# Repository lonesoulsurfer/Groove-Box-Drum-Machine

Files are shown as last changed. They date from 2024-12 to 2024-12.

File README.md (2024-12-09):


# Groove Box Drum Machine
An Arduino Nano based drum machine based on the awesome DrumKid build (https://github.com/mattybrad/drumkid) by Matt Bradshaw.  My version includes 3 X trigger outputs so you can sync with other synths.  I've also designed it so it will fit into any Eurorack and can be powered by either a standard 16 pin Eurorack power input or a 9V JST connector.

You can find a step by step guide on my Instructables page on how to build your own - https://www.instructables.com/Groove-Box-Arduino-Nano-Drum-Machine/

I have also posted a video on my YouTube page - https://youtu.be/VaNvsRpYE2A

The main goal with building this module is to create my own 'simple to build' modular synth. I wanted to keep everything as easy as possble with each module built with the following aims:

 - Can be powered by 9V (and 12V)
 - Easy to build with minimum components
 - Use Arduino to keep it simple (plus it helps to keep the components down and everything in tune)
 - Can fit into any modular synth Eurorck (include the ability to power the module via normal module power sources)
 - Has to sound great!
- Lastly, it should be portable and be powered from a 9V battery



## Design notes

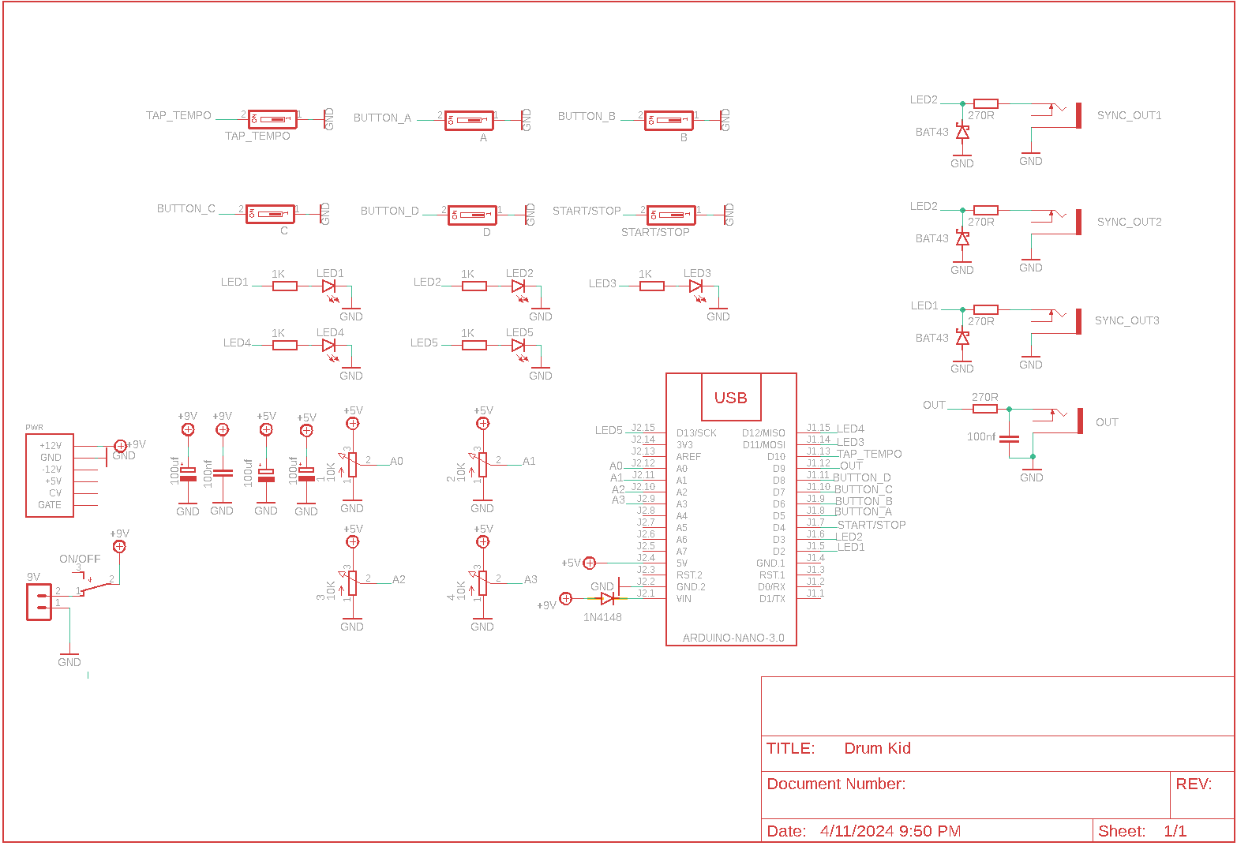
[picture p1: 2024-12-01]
Schematic.png

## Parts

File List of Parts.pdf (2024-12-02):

Part Type Value Qty | Image | Link | Notes
Capacitor Polypropylene 104J 100nf 2 | | Link (https://vi.aliexpress.com/w/wholesale-capacitor-100nf.html?spm=a2g0o.productlist.search.0)
Capacitor Polarized 100uf 3 ESR | | Link (https://vi.aliexpress.com/w/wholesale-capacitor-100uf-.html?spm=a2g0o.productlist.search.0) | I like to use high frequency, low noise capacitors

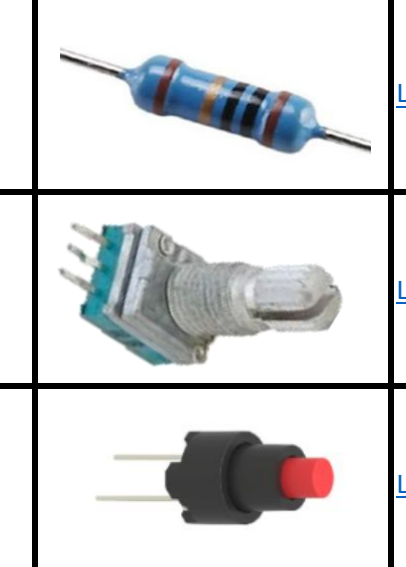
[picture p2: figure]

1K 5 Resistors Metal Film 1% 270R 4 | | Link (https://vi.aliexpress.com/w/wholesale-resistor-metal-film.html?spm=a2g0o.productlist.search.0)
Potentiometers 9mm Vertical 10K 4 | | Link (https://www.aliexpress.com/w/wholesale-9mm-vertical-potentiometer.html) | Use the metal sharft type. You can use the nut on these to help secure the front panel to the PCB
Momentary (PN SKRCADD010) 6 Switch On/Off Toggle Switch Through 1 Hole version | | Link (https://www.aliexpress.com/w/wholesale-SKRCADD010.html?spm=a2g0o.productlist.search.0) Link (https://vi.aliexpress.com/item/1005001510219617.html) | Make sure that the pins on the switch are Stich pins and are able to go through the holes in the PBC
Female Header Pin Socket 15 Pin 2 | | Link (https://vi.aliexpress.com/w/wholesale-Single-Row-Female-2.54MM-Spacing-Pin.html) | These are used to hold the Arduino into place. You could solder the Arduino onto the PCB but be careful of shorts that may happen against the components on the other side
Arduino Nano 3 1 | | Link (https://vi.aliexpress.com/w/wholesale-arduino-nano.html?spm=a2g0o.detail.search.0)

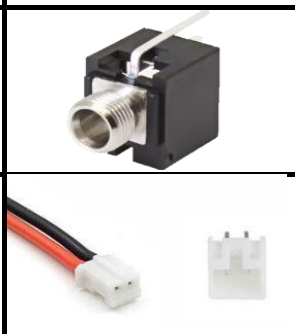
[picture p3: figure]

Audio Socket 3.5mm (PN - PJ-301M) 4 | | Link (https://vi.aliexpress.com/item/1005005352992401.html?scm_id=1007.40050.354490.0&scm-url=1007.40050.354490.0)
Mini JST Connector and wire 2 Pin 1 | | Link (https://vi.aliexpress.com/item/1005005939956886.html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) | This is used to either power the PCB or to test it. If you are going with the 9v battery then you could leave this
Bat43 - schottky 3 Doides 1N4148 | | Link (https://vi.aliexpress.com/w/wholesale-bat43-diode.html?spm=a2g0o.productlist.search.0) Link (https://vi.aliexpress.com/w/wholesale-diode-1n4148.html?spm=a2g0o.home.search.0)
LED 3mm (any colour) 5 | | Link (https://vi.aliexpress.com/w/wholesale-3mm-led-assorted.html?spm=a2g0o.productlist.search.0)

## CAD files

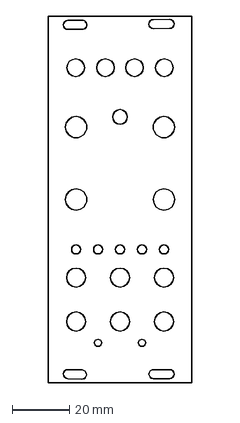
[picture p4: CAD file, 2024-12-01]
KiCad - Front Panel/Drum Kid - Fusion.dxf
50.5 x 128.5 mm

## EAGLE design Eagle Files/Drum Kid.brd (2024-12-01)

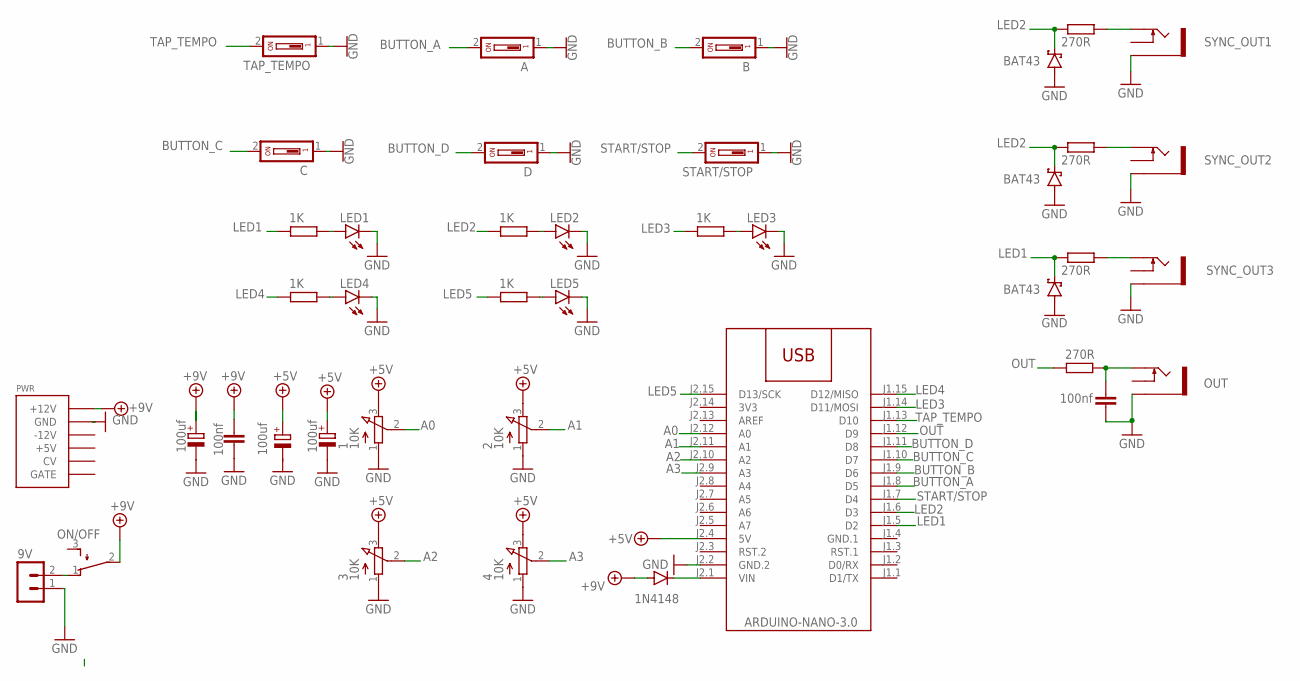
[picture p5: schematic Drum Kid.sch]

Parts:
1, 2, 3, 4: 10K; EVUF
9V: B2B-PH-K-S
A: DS01; DS-01
B: DS01; DS-01
C: DS01; DS-01
C1, C4: 100nf; C050-024X044
C2, C3: 100uf; E2-5
C5: 100uf; E2,5-6E
D: DS01; DS-01
D1, D3, D4: BAT43; DO35-10
D2: 1N4148; DO35-7
LED1, LED2, LED3, LED4, LED5: LED3MM
M1: ARDUINO-NANO-3.0
ON/OFF: TL32PO; TL3XPO
OUT: THONKICONNNEW; WQP-PJ301M-12_JACK
PWR: POWER; POWER_16
R1, R2, R3, R4, R5: 1K; 0207/10
R6, R7, R8, R9: 270R; 0207/10
START/STOP: DS01; DS-01
SYNC_OUT1, SYNC_OUT2, SYNC_OUT3: THONKICONNNEW; WQP-PJ301M-12_JACK
TAP_TEMPO: DS01; DS-01

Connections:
3V3: M1.J2.14 (3V3)
+5V: 1.3 (E), 2.3 (E), 3.3 (E), 4.3 (E), C2.+, C5.+, M1.J2.4 (5V)
+9V: C1.1, C3.+, D2.A, ON/OFF.2, PWR.9 (+12V), PWR.10 (+12V)
A0: 1.2 (S), M1.J2.12 (A0)
A1: 2.2 (S), M1.J2.11 (A1)
A2: 3.2 (S), M1.J2.10 (A2)
A3: 4.2 (S), M1.J2.9 (A3)
BUTTON_A: A.2, M1.J1.8 (D5)
BUTTON_B: B.2, M1.J1.9 (D6)
BUTTON_C: C.2, M1.J1.10 (D7)
BUTTON_D: D.2, M1.J1.11 (D8)
GND: 1.1 (A), 2.1 (A), 3.1 (A), 4.1 (A), 9V.1, A.1, B.1, C.1, C1.2, C2.-, C3.-, C4.2, D.1, D1.A, D3.A, D4.A, LED1.K (C), LED2.K (C), LED3.K (C), LED4.K (C), LED5.K (C), M1.J2.2 (GND.2), OUT.P$3_SLEEVE (SLEEVE), PWR.3 (GND), PWR.4 (GND), PWR.5 (GND), PWR.6 (GND), PWR.7 (GND), PWR.8 (GND), START/STOP.1, SYNC_OUT1.P$3_SLEEVE (SLEEVE), SYNC_OUT2.P$3_SLEEVE (SLEEVE), SYNC_OUT3.P$3_SLEEVE (SLEEVE), TAP_TEMPO.1
GND.1: M1.J1.4 (GND.1)
LED1: D3.C, M1.J1.5 (D2), R1.1, R6.1
LED2: D1.C, D4.C, M1.J1.6 (D3), R3.1, R7.1, R9.1
LED3: M1.J1.14 (D11/MOSI), R5.1
LED4: M1.J1.15 (D12/MISO), R2.1
LED5: M1.J2.15 (D13/SCK), R4.1
unnamed: 9V.2, ON/OFF.1 (O)
unnamed: LED1.A, R1.2
unnamed: C4.1, OUT.P$1_TIP (TIP), R8.2
unnamed: LED4.A, R2.2
unnamed: LED5.A, R4.2
unnamed: LED2.A, R3.2
unnamed: LED3.A, R5.2
unnamed: R7.2, SYNC_OUT1.P$1_TIP (TIP)
unnamed: R6.2, SYNC_OUT3.P$1_TIP (TIP)
unnamed: R9.2, SYNC_OUT2.P$1_TIP (TIP)
unnamed: D2.C, M1.J2.1 (VIN)
OUT: M1.J1.12 (D9), R8.1
START/STOP: M1.J1.7 (D4), START/STOP.2
TAP_TEMPO: M1.J1.13 (D10), TAP_TEMPO.2

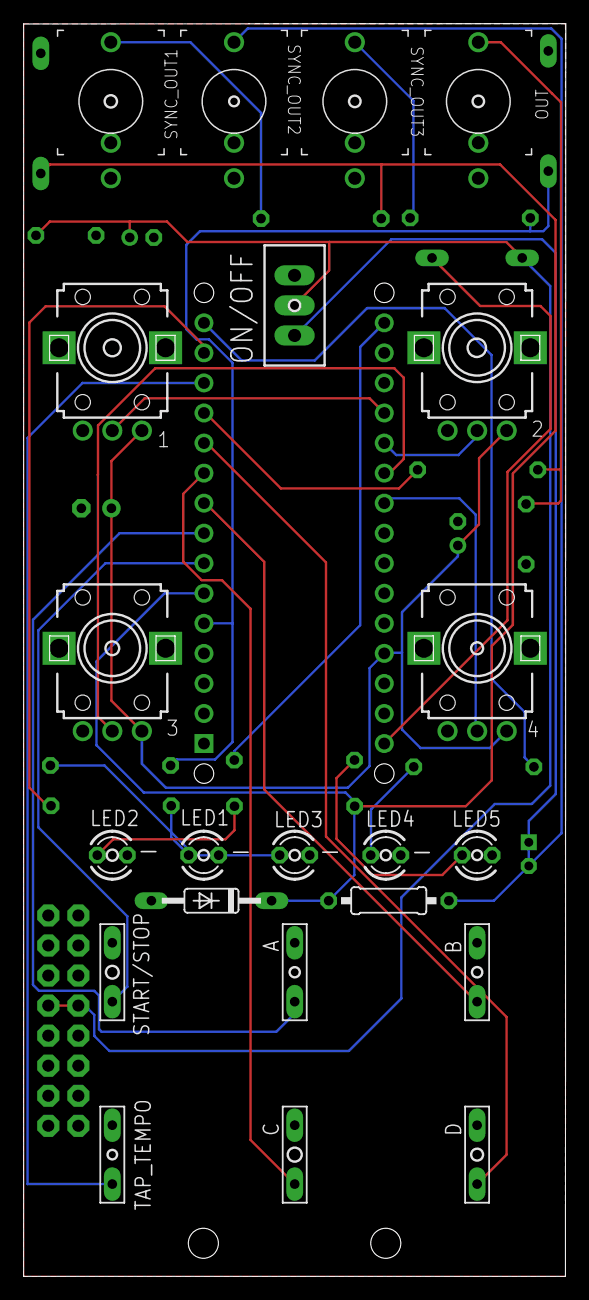
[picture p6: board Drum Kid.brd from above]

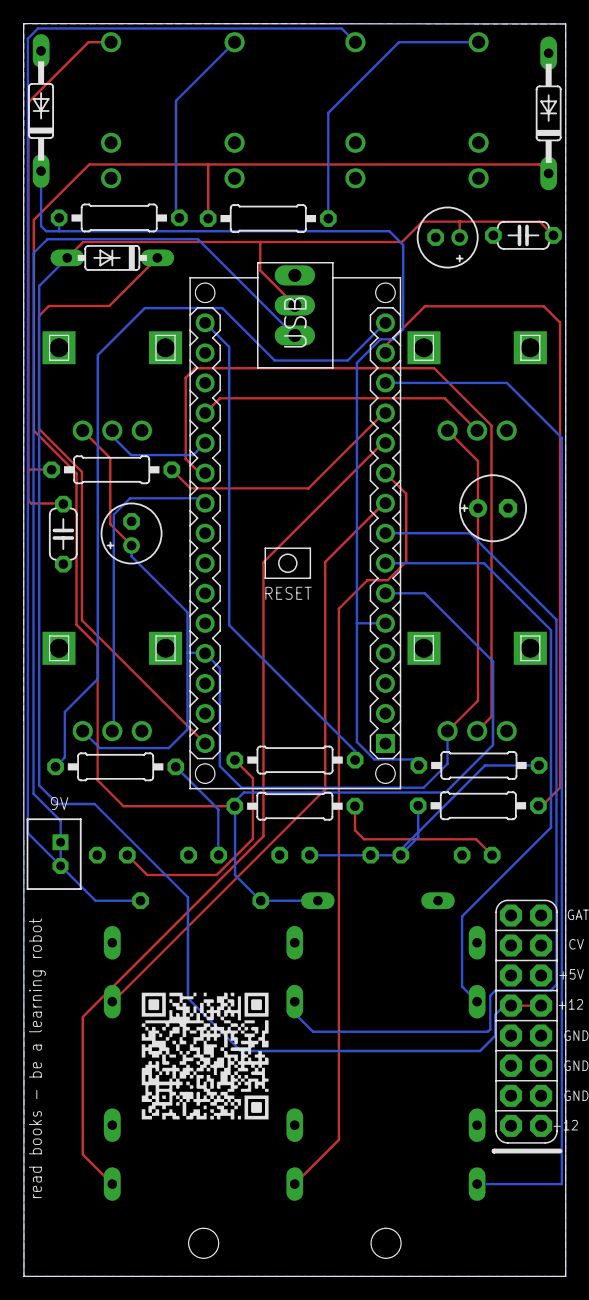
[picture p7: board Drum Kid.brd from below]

Board: 2 copper layers, 45.8 x 105.9 mm, 41 parts (19 on the bottom side), 30 nets.

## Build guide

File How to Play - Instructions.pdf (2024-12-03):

Basic Functions

- Press the start/stop button to start or stop the rhythm
- Press buttons A/B/C/D to select different knob functions (see table below)
- Turn any of the four knobs to alter the parameters in the current selected group (see table below)
- Tap the tap tempo button repeatedly to set the tempo
- Press buttons A+B together to load a session, then choose which session to load by pressing any of the buttons (or press multiple buttons together to cancel)
- Press buttons C+D together to save a session, then choose which slot to save your session in by pressing any of the buttons (or press multiple buttons together to cancel)
- Press buttons B+C together to change the current active memory bank, then choose a specific memory bank by pressing any of the buttons

Other functions

A few extra hidden functions:

- Press buttons A+B+C together to reset your beat to default values. This will not affect any saved beats
- Press buttons A+B+D together to generate a random beat. This will also not affect any saved beats

Parameters

There are 16 different parameters which can be adjusted on DrumKid, split into four groups, with each group's four parameters controlled by the four knobs. The parameters are grouped as follows:

Group A (randomness)

1. Chance
2. Zoom
3. Range
4. Midpoint

Group B (effects)

1. Pitch
2. Crush
3. Crop
4. Drop

Group C (drone)

1. Drone
2. Modulate
3. Tuning
4. Note

Group D (rhythm)

1. Beat
2. Beats/bar (time signature)
3. Swing
4. Tempo

You can try out each parameter by starting a rhythm (using the start/stop button), then selecting a group and turning the different knobs. For example, try selecting group B (by pressing the B button) then turning the first knob, which will now control "pitch". You should hear the sound change. Below are descriptions of exactly what each parameter does, and how it can be used.

Chance - The probability of extra drum hits being generated. At zero, the beat will be completely unchanged, while for higher values there will be lots of extra events, usually creating a busier, messier beat. This can be used in conjunction with zoom, midpoint, and range to create drum fills that transition organically from a simple beat.

Zoom - Chooses which subdivision of the beat should be affected by the randomly generated extra hits. When zoom is at zero, beats will only be generated for "whole notes" (i.e. the first beat of the bar). Higher values will affect half notes, quarter notes, eighth notes, and so on. A medium value is a good place to start for zoom, but turning it up can make a beat or fill sound more "urgent". Some of the smaller subdivisions will vary depending on the current "swing" setting.

Range - This is the range of velocities which will be assigned to the random hits, and works in conjunction with "midpoint" (see below). For all the random hits to have the same velocity as each other, keep this value at zero. For a wide range of velocities, turn this up high.

Midpoint - This is the average velocity of the randomly generated hits, and works in conjunction with "range". Note that this control does allow negative values (below halfway). If you set the midpoint to maximum and have range set at zero, all the randomly generated hits will be at max velocity. Conversely, if you set it at zero, some hits will be muted. Setting it somewhere in the middle (with non-zero range) will add some random hits while reducing the volume of others. Try keeping midpoint at a three-quarters setting to add a bustling undercurrent to your beat, or turn it up briefly to create a drum fill.

Pitch - Alters the playback speed of the samples. Will play samples backwards if you turn the knob below halfway.

Crush - Reduces the number of bits used to calculate the audio output, creating a digital distortion effect. Higher values are clean, lower values are more distorted (fewer bits).

Crop - Crops the end of the samples, creating a staccato effect. Lower values are more cropped.

Drop - This control mutes some or all of the drum channels, allowing you to quickly "drop" everything except the hi-hat and snare, for example, or only retain the kick drum. Broadly, this control has "treble-y" channels at one end and "bass-y" channels at the other. The setting corresponding to all the channels being audible is somewhere in the middle.

Drone - generates a drone which can be mixed with the drum sounds. The "drone" parameter controls the amount of raw drone signal added to the mix. Turning to the left adds a single tone, while turning to the right adds two tones, a fifth apart. A halfway value mutes the drone.

Modulation - The drone can also used to modulate the audio signal from the drums, creating a robotic effect. When "modulation" is set at halfway, no effect is heard. Turning the knob to the left modulates the drums with a single drone, while turning it to the right modulates the drums with two tones, a fifth apart. Turning the knob all the way left or right creates an extreme effect, while values closer to halfway will be more subtle.

Tuning - Controls the overall tuning of the drones (both the single and fifth tones).

Note - Alter the root note of the drones, in semitone steps over an octave range.

Beat - Chooses between a series of basic underlying drum patterns (see "preset beat list" below).

Beats/bar - Alters the time signature of the beat, i.e. the number of steps in the pattern. You can have between 1 and 13 beats in a bar, or if you turn the knob all the way to the right, the time signature will be randomised at the start of each bar.

Swing - Creates a swing feel to a beat by altering the timing of certain hits. There are three settings: straight, partial swing, and full (triplet) swing.

Tempo - Alters the tempo (BPM) of the beat. Will override any tempo previously set using the tap tempo function. Has a range of 10BPM to ~1000BPM, with the "sensible" tempos grouped in the middle of the range.

Pre-set beat list

The pre-set beats can be accessed via hitting button D and turning pot 1.

Beat - Chooses between a series of basic underlying drum patterns

Please note that the LED pattern for each beat is illustrated to help you find the correct beat.

1. You can leave your hat on ⚫⚪⚪⚪⚪
2. Johnny Two-Hats ⚪⚫⚪⚪⚪
3. Drum lesson ⚪⚪⚫⚪⚪
4. Half-time rock ⚪⚪⚪⚫⚪
5. There there ⚪⚪⚪⚪⚫
6. Metal ⚫⚪⚪⚪⚪
7. Four to the floor ⚪⚫⚪⚪⚪
8. "Dance" ⚪⚪⚫⚪⚪
9. Blue Monday ⚪⚪⚪⚫⚪
10. Chime ⚪⚪⚪⚪⚫
11. Funk Soul Brother ⚫⚪⚪⚪⚪
12. Amen I ⚪⚫⚪⚪⚪
13. Amen I ⚪⚪⚫⚪⚪
14. Superstition ⚪⚪⚪⚫⚪
15. Derribar el muro ⚪⚪⚪⚪⚫
16. Hips don't lie ⚫⚪⚪⚪⚪
17. Videotape ⚪⚫⚪⚪⚪
18. Videotape (Bonnaroo) ⚪⚪⚫⚪⚪
19. Military ⚪⚪⚪⚫⚪
20. Ballad ⚪⚪⚪⚪⚫

21. Waltz ⚫⚪⚪⚪⚪
22. Take Five ⚪⚫⚪⚪⚪
23. Unsquare ⚪⚪⚫⚪⚪
24. Nihil ⚪⚪⚪⚫⚪

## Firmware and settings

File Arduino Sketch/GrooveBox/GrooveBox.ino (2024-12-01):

/*  DrumKid firmware V1.2
 *  This code should work for DrumKid boards from V6 onwards.
 *  It might work with earlier versions with a bit of tweaking :) 
 */

// include debouncing library to make buttons work reliably
#include "src/Bounce2/src/Bounce2.h"

// include Mozzi library files for generating audio (custom version to allow reverse playback)
#include "src/MozziDK/src/MozziGuts.h"
#include "src/MozziDK/src/Sample.h"
#include "src/MozziDK/src/mozzi_rand.h"
#include "src/MozziDK/src/Oscil.h"
#include "src/MozziDK/src/tables/saw256_int8.h"

// include drum beat pattern definitions from separate file
#include "beats.h"

// include sample data (generated via Python script)
#include "sample0.h"
#include "sample1.h"
#include "sample2.h"
#include "sample3.h"
#include "sample4.h"

// declare samples as Mozzi sample objects
Sample <sample0_NUM_CELLS, AUDIO_RATE> sample0(sample0_DATA);
Sample <sample1_NUM_CELLS, AUDIO_RATE> sample1(sample1_DATA);
Sample <sample2_NUM_CELLS, AUDIO_RATE> sample2(sample2_DATA);
Sample <sample3_NUM_CELLS, AUDIO_RATE> sample3(sample3_DATA);
Sample <sample4_NUM_CELLS, AUDIO_RATE> sample4(sample4_DATA);

// define oscillators for drone
Oscil<SAW256_NUM_CELLS, AUDIO_RATE> droneOscillator1(SAW256_DATA);
Oscil<SAW256_NUM_CELLS, AUDIO_RATE> droneOscillator2(SAW256_DATA);

// include EEPROM library for saving data
#include <EEPROM.h>

// declare buttons as Bounce objects
Bounce buttons[6];

// Mozzi control rate, measured in Hz, must be power of 2
// try to keep this value as high as possible (256 is good) but reduce if having performance issues
#define CONTROL_RATE 128

// define various values
#define NUM_KNOBS 4
#define NUM_LEDS 5
#define NUM_BUTTONS 6
#define NUM_SAMPLES 5
#define NUM_PARAM_GROUPS 4
#define SAVED_STATE_SLOT_BYTES 24
#define NUM_TAP_TIMES 8
#define MAX_BEATS_PER_BAR 13

// define pin numbers
// keep pin 9 for audio, but others can be changed to suit your breadboard layout
const byte ledPins[5] = {2,3,11,12,13};
const byte buttonPins[6] = {4,5,6,7,8,10};
const byte analogPins[4] = {A0,A1,A2,A3};

// various other global variables
float nextPulseTime = 0.0; // the time, in milliseconds, of the next pulse
float msPerPulse = 20.8333; // time for one "pulse" (there are 24 pulses per quarter note, as defined in MIDI spec)
byte pulseNum = 0; // 0 to 23 (24ppqn, pulses per quarter note)
unsigned int stepNum = 0; // 0 to 192 (max two bars of 8 beats, aka 192 pulses)
unsigned int numSteps; // number of steps used - dependent on time signature
unsigned int specialOffset = 0; // number of steps to offset pattern in random time signature mode
bool beatPlaying = false; // true when beat is playing, false when not
byte noteDown = B00000000; // keeps track of whether a MIDI note is currently down or up
bool syncReceived = false; // has a sync/clock signal been received? (IMPROVE THIS LATER)
byte midiNotes[NUM_SAMPLES]; // MIDI note numbers
const byte defaultMidiNotes[NUM_SAMPLES] = {36,42,38,37,43}; // default MIDI note numbers
byte midiNoteCommands[NUM_SAMPLES]; // MIDI note on commands
byte sampleVolumes[NUM_SAMPLES] = {0,0,0,0,0}; // current sample volumes
byte storedValues[NUM_PARAM_GROUPS*NUM_KNOBS]; // analog knob values, one for each parameter (so the value can be remembered even after switching groups)
byte firstLoop = true; // allows special actions on first loop
byte secondLoop = false; // allows special actions on second loop
bool newMidiDroneRoot = false;
byte controlSet = 0; // current active set of parameters
byte knobLocked = B11111111; // record whether a knob's value is currently "locked" (i.e. won't alter effect until moved by a threshold amount)
byte analogValues[NUM_KNOBS]; // current analog (knob) values
byte initValues[NUM_KNOBS]; // initial parameter values
byte specialLedDisplayNum; // binary number to display on LEDs (when needed)
unsigned long specialLedDisplayTime = 0; // the last time the LEDs were told to display a number

// save/load variables
bool readyToChooseSaveSlot = false;
bool readyToChooseLoadSlot = false;
bool readyToChooseBank = false;
bool newStateLoaded = false;
byte activeBank = 0;
byte activeMidiSettingsNum = 0;

// tempo variables
float tapTimes[NUM_TAP_TIMES];
byte nextTapIndex = 0;

// parameter variables, each with a range of 0-255 unless otherwise noted
byte paramChance;
byte paramZoom;
int paramMidpoint; // -255 to 255
int paramRange; // 0 to 510
byte paramPitch;
byte paramCrush;
byte paramCrop;
byte paramDrop;
byte paramBeat; // 0 to 23 (24 beats in total)
byte paramTimeSignature; // 1 to 13 (3/4, 4/4, 5/4, 6/4, 7/4)
float paramTempo; 
byte paramSwing = 0; // 0 to 2 (0=straight, 1=approx quintuplet swing, 2=triplet swing)
byte paramDroneRoot; // 0 to 11 (all 12 possible semitones in an octave)
float paramDronePitch;
byte paramDroneMod;

// special global variables needed for certain parameters
byte crushCompensation;
byte previousBeat;
byte previousDroneRoot;
byte activeDroneRoot;
byte previousTimeSignature;
byte oscilGain1 = 255;
byte oscilGain2 = 255;
bool droneMod2Active = false;
#define MIN_TEMPO 40
#define MAX_TEMPO 295

#if MIN_TEMPO + 255 != MAX_TEMPO
#error "Tempo must have a range of exactly 255 otherwise I'll have to write more code"
#endif

// define which knob controls which parameter
// e.g. 0 is group 1 knob 1, 6 is group 2 knob 3
#define CHANCE 0
#define ZOOM 1
#define RANGE 2
#define MIDPOINT 3

#define PITCH 4
#define CRUSH 5
#define CROP 6
#define DROP 7

#define DRONE 8
#define DRONE_MOD 9
#define DRONE_PITCH 10
#define DRONE_ROOT 11

#define BEAT 12
#define TIME_SIGNATURE 13
#define SWING 14
#define TEMPO 15

// define root notes
float rootNotes[13] = {
  138.5913155f,
  146.832384f,
  155.5634919f,
  164.8137785f,
  174.6141157f,
  184.9972114f,
  195.997718f,
  207.6523488f,
  220.0f,
  233.0818808f,
  246.9416506f,
  261.6255653f,
  277.182631f,
};

// determines whether each sample is played or muted in a particular drop mode
byte dropRef[NUM_SAMPLES] = {
  B00011110, // kick
  B11111000, // hat
  B00110000, // snare
  B01111000, // rim
  B00011100, // tom
};

void setup(){
  byte i;

  checkEepromScheme(); // write defaults to memory if not previously done
  initialiseSettings(false);
  
  for(i=0;i<NUM_LEDS;i++) {
    pinMode(ledPins[i],OUTPUT); // set LED pins as outputs
  }

  randSeed((long)analogRead(4)*analogRead(5)); // A4 and A5 should be floating, use to seed random numbers
  startMozzi(CONTROL_RATE);

  // initialise all buttons using Bounce2 library
  for(i=0; i<NUM_BUTTONS; i++) {
    buttons[i].interval(25);
    buttons[i].attach(buttonPins[i], INPUT_PULLUP);
  }

  // set starting values for each parameter
  resetSessionToDefaults();
  
  Serial.begin(31250); // begin serial communication for MIDI input/output
  //Serial.begin(9600);

  flashLeds(); // do a brief LED light show to show the unit is working
}

byte buttonsPressed = 0;
byte buttonGroup = 0;
byte lastButtonsPressed = 0;
byte menuState = 0;

void updateControl(){
  byte i;
  bool controlSetChanged = false;
  newStateLoaded = false;
  byte prevControlSet = controlSet;
  
  for(i=0; i<6; i++) {
    buttons[i].update();
  }
  for(i=0; i<6; i++) {
    bitWrite(buttonsPressed,i,!buttons[i].read());
    buttonGroup = buttonsPressed | buttonGroup;
  }
  if(buttonsPressed != lastButtonsPressed) {
    if(menuState == 0) {
      if(buttons[0].fell()) {
        if(!beatPlaying) startBeat();
        else stopBeat();
      }
      if(buttons[5].fell()) {
        tapTimes[nextTapIndex] = (float) millis();

        float firstTime;
        float timeTally = 0.0;
        byte validTimes = 0;
        bool keepChecking = true;
        for(i=0;i<NUM_TAP_TIMES-1 && keepChecking;i++) {
          byte thisTapIndex = (nextTapIndex + NUM_TAP_TIMES - i) % NUM_TAP_TIMES;
          byte lastTapIndex = (nextTapIndex + NUM_TAP_TIMES - i - 1) % NUM_TAP_TIMES;
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
void loop(){
  while(Serial.available()) {
    thisMidiByte = Serial.read();
    if(bitRead(thisMidiByte,7)) {
      // status byte
      midiBytes[0] = thisMidiByte;
      if(thisMidiByte==0xFA) {
        // clock start signal received
        startBeat();
      } else if(thisMidiByte==0xFB) {
        // clock continue signal received
        startBeat();
      } else if(thisMidiByte==0xFC) {
        // clock stop signal received
        stopBeat();
      } else if(thisMidiByte==0xF8) {
        // clock signal received
        syncReceived = true;
        if(beatPlaying) {
          doPulseActions();
        }
      }
      currentMidiByte = 1;
    } else {
      // data byte
      midiBytes[currentMidiByte] = thisMidiByte;
      if((midiBytes[0]>>4)==0xB && currentMidiByte == 2) {
        // CC message (any channel)
        if(midiBytes[1]>=16&&midiBytes[1]<32) {
          byte paramNum = midiBytes[1] - 16;
          byte paramSet = paramNum / 4;
          byte paramSetNum = paramNum % 4;
          storedValues[paramNum] = midiBytes[2] * 2;
          if(controlSet==paramSet) {
            bitWrite(knobLocked, paramSetNum, true);
            initValues[paramSetNum] = analogValues[paramSetNum];
          }
          updateParameters(paramSet);
        }
      } else if((midiBytes[0]>>4)==0x9 && currentMidiByte == 2) {
        // Note on (any channel)
        if(midiBytes[2] > 0) {
          newMidiDroneRoot = true;
          byte paramSet = DRONE_ROOT / 4;
          byte paramSetNum = DRONE_ROOT % 4;
          storedValues[DRONE_ROOT] = (midiBytes[1] % 12) * 20;
          if(controlSet==paramSet) {
            bitWrite(knobLocked, paramSetNum, true);
            initValues[paramSetNum] = analogValues[paramSetNum];
          }
          updateParameters(paramSet);
          newMidiDroneRoot = false;
        }
      }
      // MIDI thru, experimental, only certain message types
      bool useMidiThru = false;
      if(useMidiThru) {
        if(currentMidiByte == 2) {
          switch(midiBytes[0]>>4) {
            case 0xB:
            // CC
            case 0x9:
            // note on
            case 0x8:
            // note off
            Serial.write(midiBytes[0]);           
            Serial.write(midiBytes[1]);
            Serial.write(midiBytes[2]);
            break;
          }
        }
      }
      currentMidiByte ++;
    }
  }
  audioHook(); // main Mozzi function, calls updateAudio and updateControl
}

void flashLeds() {
  byte i, randByte;
  for(i=0;i<30;i++) {
    randByte = rand(0,256);
    displayLedNum(randByte);
    while(millis()<(i+1)*25) {
      // do nothing here
      // this is a silly hack so that the delay() function doesn't get compiled
      // this is what happens when your program takes up 99%+ of the storage space
    }
  }
  displayLedNum(0);
}

void updateLeds() {
  if(millis() < specialLedDisplayTime + 750UL && specialLedDisplayTime > 0) {
    // show desired binary number for certain parameters where visual feedback is helpful
    displayLedNum(specialLedDisplayNum);
  } else if(beatPlaying && menuState == 0) {
    //if(stepNum==0||(paramTimeSignature==4&&stepNum==96)||(paramTimeSignature==6&&stepNum==72)) displayLedNum(B00000011);
    if(stepNum==0) displayLedNum(B00000011);
    else if(stepNum%24==0) displayLedNum(B00000010);
    else if(stepNum%24==3) displayLedNum(B00000000);
  } else {
    displayLedNum(B00000000);
  }
}

void displayLedNum(byte displayNum) {
  byte i;
  for(i=0;i<NUM_LEDS;i++) {
    digitalWrite(ledPins[i], bitRead(displayNum,i));
  }
}

void specialLedDisplay(byte displayNum, bool isBinary) {
  if(!firstLoop&&!secondLoop) {
    if(isBinary) {
      specialLedDisplayNum = displayNum;
    } else {
      specialLedDisplayNum = B00000000;
      bitWrite(specialLedDisplayNum,displayNum%NUM_LEDS,HIGH);
    }
    specialLedDisplayTime = millis();
  }
}

float byteToTempo(byte tempoByte) {
  float tempoFloat;
  if(tempoByte<=192) {
    tempoFloat = 10.0 + tempoByte;
  } else {
    tempoFloat = 202.0 + 12.66667 * (tempoByte - 192.0);
  }
  return tempoFloat;
}

byte tempoToByte(float tempoFloat) {
  byte tempoByte;
  if(tempoFloat<=202.0) {
    tempoByte = ((byte) tempoFloat) - 10;
  } else {
    tempoByte = (byte) ((tempoFloat - 202.0) / 12.66667) + 192;
  }
  return tempoByte;
}

void chooseBank(byte newBank) {
  activeBank = newBank;
  readyToChooseBank = false;
}

void resetSessionToDefaults() {
  // set starting values for each parameter
  storedValues[CHANCE] = 128;
  storedValues[ZOOM] = 150;
  storedValues[RANGE] = 0;
  storedValues[MIDPOINT] = 128;
  
  storedValues[PITCH] = 160;
  storedValues[CRUSH] = 255;
  storedValues[CROP] = 255;
  storedValues[DROP] = 128;

  storedValues[DRONE_MOD] = 127;
  storedValues[DRONE] = 127;
  storedValues[DRONE_ROOT] = 0;
  storedValues[DRONE_PITCH] = 127;

  storedValues[BEAT] = 27;
  storedValues[TIME_SIGNATURE] = 64; // equates to 4/4
  storedValues[SWING] = 0;
  storedValues[TEMPO] = 110; // actually equates to 120BPM

  newStateLoaded = true;
  for(byte i=0;i<NUM_PARAM_GROUPS;i++) {
    updateParameters(i); // set parameters to initial values defined above
  }
}

void createRandomSession() {
  storedValues[CHANCE] = rand(64,192);
  storedValues[ZOOM] = rand(100,190);
  storedValues[RANGE] = rand(0,128);
  storedValues[MIDPOINT] = rand(80,190);
  
  storedValues[PITCH] = rand(135,256);
  if(rand(0,6)==0) storedValues[PITCH] = rand(0,120);
  storedValues[CRUSH] = rand(160,256);
  storedValues[CROP] = rand(128,256);
  storedValues[DROP] = 128;
  if(rand(0,3)==0) storedValues[DROP] = rand(29,226);

  storedValues[DRONE_MOD] = 127;
  storedValues[DRONE] = 127;
  storedValues[DRONE_ROOT] = rand(0,256);
  storedValues[DRONE_PITCH] = 127;
  if(rand(0,6)==0) storedValues[DRONE_MOD] = rand(0,256);
  if(rand(0,4)==0) storedValues[DRONE] = rand(64,192);

  storedValues[BEAT] = rand(0,240);

  if(!beatPlaying) {
    // don't randomise time signature and tempo unless stopped
    storedValues[TIME_SIGNATURE] = 64; // equates to 4/4
    if(rand(0,3)==0) storedValues[TIME_SIGNATURE] = rand(0,256);
    storedValues[TEMPO] = rand(70,160);
    if(rand(0,4)==0) storedValues[TEMPO] = rand(0,256);
  }
  storedValues[SWING] = rand(0,256);

  newStateLoaded = true;
  for(byte i=0;i<NUM_PARAM_GROUPS;i++) {
    updateParameters(i); // set parameters to initial values defined above
  }
}

void loadParams(byte slotNum) {
  readyToChooseLoadSlot = false;
  newStateLoaded = true;
  for(byte i=0; i<NUM_PARAM_GROUPS*NUM_KNOBS; i++) {
    if(!(i==TEMPO&&beatPlaying)) {
      byte thisValue = EEPROM.read((slotNum+6*activeBank)*SAVED_STATE_SLOT_BYTES+i);
      storedValues[i] = thisValue;
    }
  }
  for(byte i=0;i<NUM_PARAM_GROUPS;i++) {
    updateParameters(i);
  }
}

void saveParams(byte slotNum) {
  // 1024 possible byte locations in EEPROM
  // currently need 16 bytes per saved state (4 groups of 4 params, 1 byte per param)
  // 36 possible save slots (6 banks of 6 slots)
  // need to leave space for some possible extra saved state data in future
  // allot 24 bytes per saved state (vaguely round number in binary), taking up total of 864 bytes
  readyToChooseSaveSlot = false;
  for(byte i=0; i<NUM_PARAM_GROUPS*NUM_KNOBS; i++) {
    EEPROM.write((slotNum+6*activeBank)*SAVED_STATE_SLOT_BYTES+i, storedValues[i]);
  }
}

// prior to firmware version 1.1, no way of knowing whether older firmware was previously installed
// from V1.1 onwards, new special address beyond the 864 bytes reserved for storing sessions
// Slot 864-865: if these bytes have values 119 and 206 respectively, we are using the new memory system (1 in 65,025 chance of these being randomly correct)
// Slot 866: current version (0 = V1.1, 1 = V1.2)
// Slots 867-871: reserved for other version stuff if needed
// Slots 872-879: MIDI note numbers for channels 1 through 5 (and another 3 reserved)
// Slots 880-887: MIDI channel numbers for channels 1 through 5 (and another 3 reserved)
// Slots 888+: free for future features

void checkEepromScheme() {
  byte i;
  byte check1 = EEPROM.read(864);
  byte check2 = EEPROM.read(865);
  if(check1==119&&check2==206) {
    // all good, already using the new EEPROM scheme

    // update firmware version in memory if needed
    if(EEPROM.read(866) != 1) EEPROM.write(866, 1);
  } else {
    // prepare EEPROM for new scheme
    EEPROM.write(864, 119);
    EEPROM.write(865, 206);
    EEPROM.write(866, 1);
    // write default MIDI note/channel settings
    for(i=0; i<NUM_SAMPLES; i++) {
      EEPROM.write(872+i, defaultMidiNotes[i]);
      EEPROM.write(880+i, 9); // channel 10 (actually 9 because zero-indexed) is default channel to use
    }
  }
}
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

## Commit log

2024-12-01 Drum Machine
    [Drum Kid.brd, Drum Kid.sch]
2024-12-01 added Inkscape and kicad files
    [Drum Kid - Fusion.dxf, KiCad - Drum Kid.kicad_pcb, KiCad - Drum Kid.kicad_sch]
2024-12-01 Added Arduino Sketch
2024-12-04 Update Groove Box - PCB.zip

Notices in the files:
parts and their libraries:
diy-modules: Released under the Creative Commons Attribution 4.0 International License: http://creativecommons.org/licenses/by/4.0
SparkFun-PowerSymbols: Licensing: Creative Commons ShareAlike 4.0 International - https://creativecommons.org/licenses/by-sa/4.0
